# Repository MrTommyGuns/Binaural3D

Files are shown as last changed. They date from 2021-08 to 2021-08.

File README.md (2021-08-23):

# Binaural3D
TFG: "Diseño de un Micrófono Biaural para Captación de Sonido Realista"

## Resumen

Diseño e implementación de un micrófono
biaural para la captación de sonidos realistas. Consta de electrónica analógica y un diseño
tridimensional realizado mediante impresión 3D FDM.

Para el diseño 3D se partió de recursos libres de derechos para la modificación, a partir
de los cuales se llevó a cabo una total remodelación para garantizar un sistema modular
con el que realizar diferentes grabaciones dependiendo de las suposiciones requeridas. Por
consiguiente, mediante el intercambio de piezas de una misma unidad se puede variar la
ubicación de la cápsula microfónica en el oído emulado, el tamaño y forma de las orejas,
siendo estos parámetros fundamentales para generar una sensación psicoacústica correcta
para cada individuo. De este modo, se consigue un sistema muy versátil.

El circuito electrónico consiste en un preamplificador de varias etapas, donde se amplifica
la señal recogida por las cápsulas microfónicas situadas en el diseño 3D que recrea
una cabeza, simulando la captación de sonidos del oído humano. Para la implementación
de este circuito electrónico, se han llevado a cabo diferentes etapas. En primer lugar se
realizó el estudio de las cápsulas microfónicas de tipo electret, para su posterior acondicionamiento
y amplificación. Posteriormente mediante simulación se realizó un primer
circuito preamplificador simple y el primer prototipo mediante protoboard. Una vez alcanzados
unos resultados satisfactorios se inició el proceso de diseño de la PCB, incrementando
la complejidad del circuito mediante la implementación de nuevas configuraciones
de amplificación y la adhesión de un sistema de balanceo de la señal. Se realizaron una serie
de medidas eléctricas para la verificación del correcto funcionamiento y se corrigieron
los errores encontrados. Finalmente, se realizó el circuito final junto a la PCB definitiva y
se realizaron test de funcionamiento y caracterización.

CabezaFull4

PruebaSegundoPrototipo





## Vídeo

https://youtu.be/iz7Ld4p7Zro

https://youtu.be/ZWAR-ZuT80Q

## Autor

### Tomás Criado Galache

## Palabras clave

Micrófono Biaural; Preamplificador; Impresión 3D

Key words: Binaural Microphone; Preamplifier; 3D Print

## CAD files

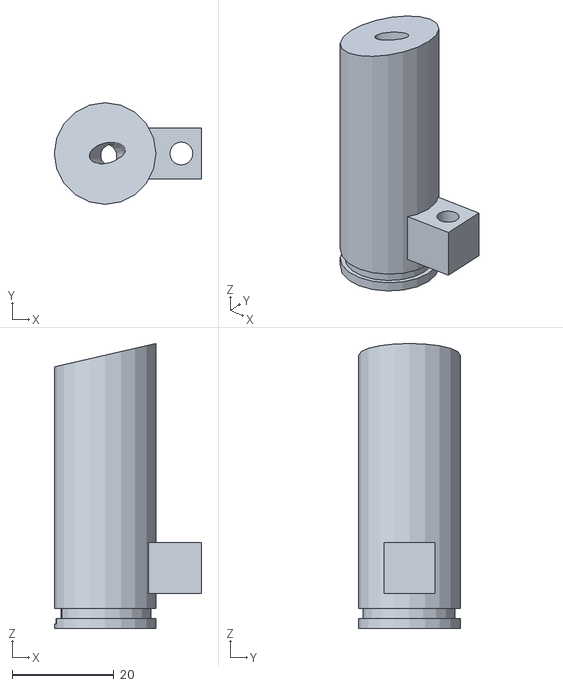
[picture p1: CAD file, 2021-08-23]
3D/Biaural_capsulemodule_R_V2.stl
29.0 x 20.0 x 56.1

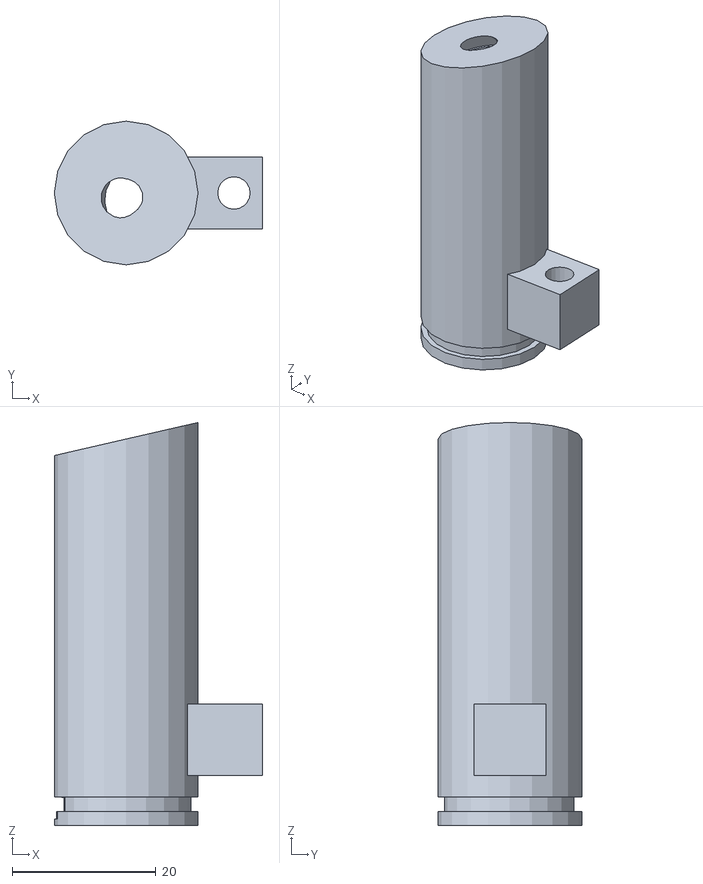
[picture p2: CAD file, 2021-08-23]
3D/Biaural_capsulemodule_R_No_Conducto.stl
29.0 x 20.0 x 56.1

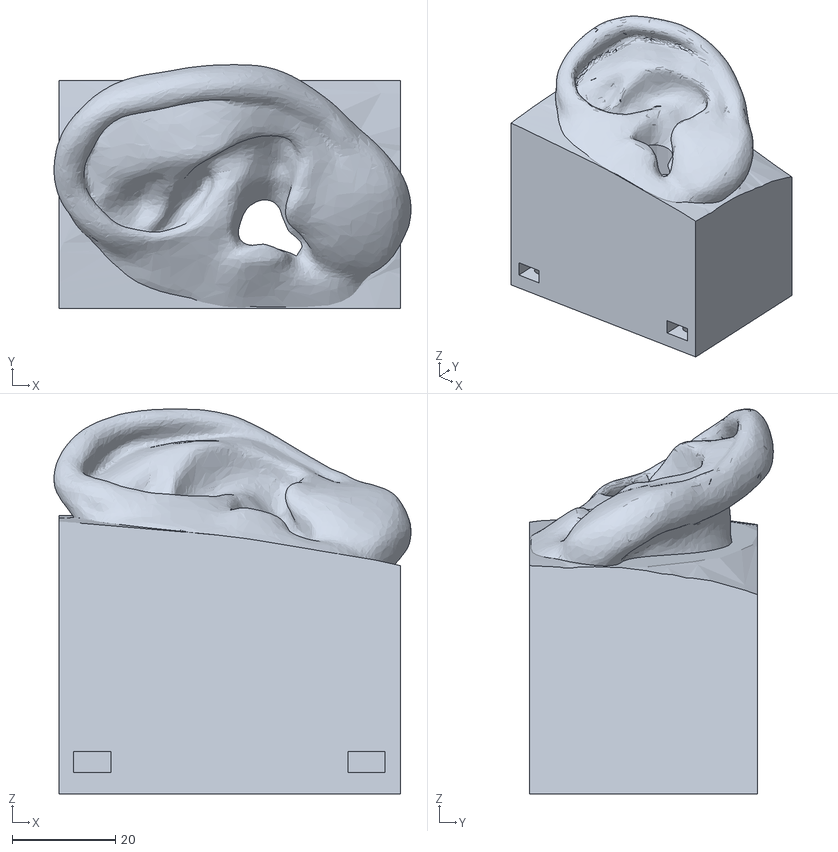
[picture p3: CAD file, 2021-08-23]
3D/Biaural_L_ear_V3.stl
69.0 x 47.1 x 74.4

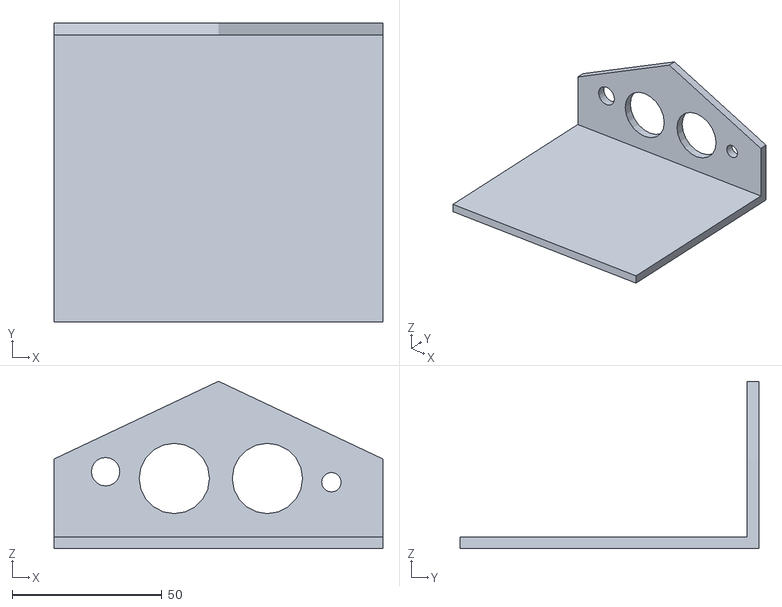
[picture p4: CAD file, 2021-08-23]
3D/Frontal Electronica.stl
110.0 x 100.0 x 56.0

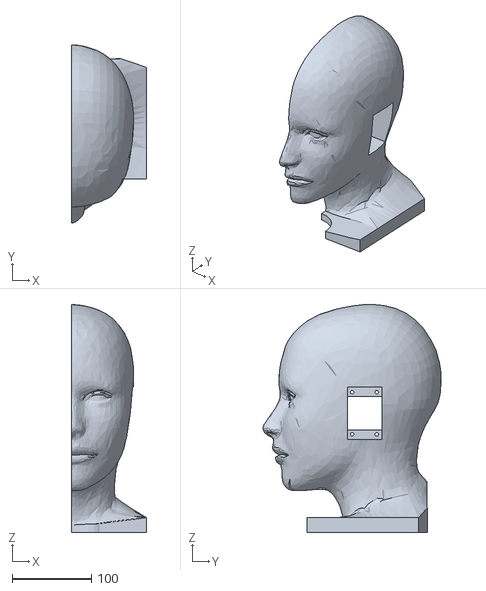
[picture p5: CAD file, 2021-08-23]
3D/Biaural_head_L_V4.stl
94.0 x 224.3 x 287.0

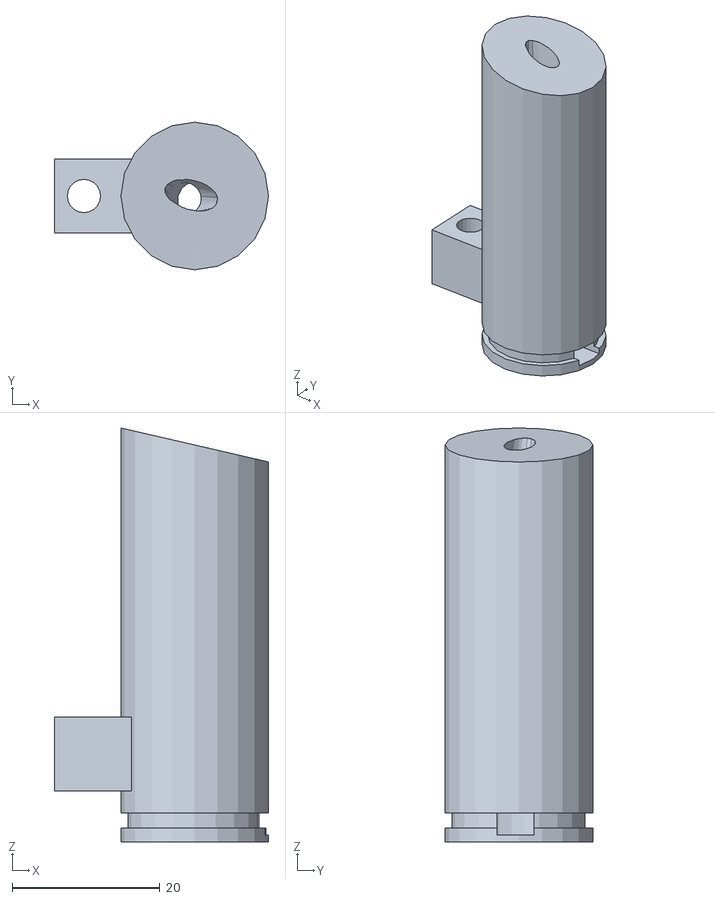
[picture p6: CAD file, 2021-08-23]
3D/Biaural_capsulemodule_L_V2.stl
29.0 x 20.0 x 56.1

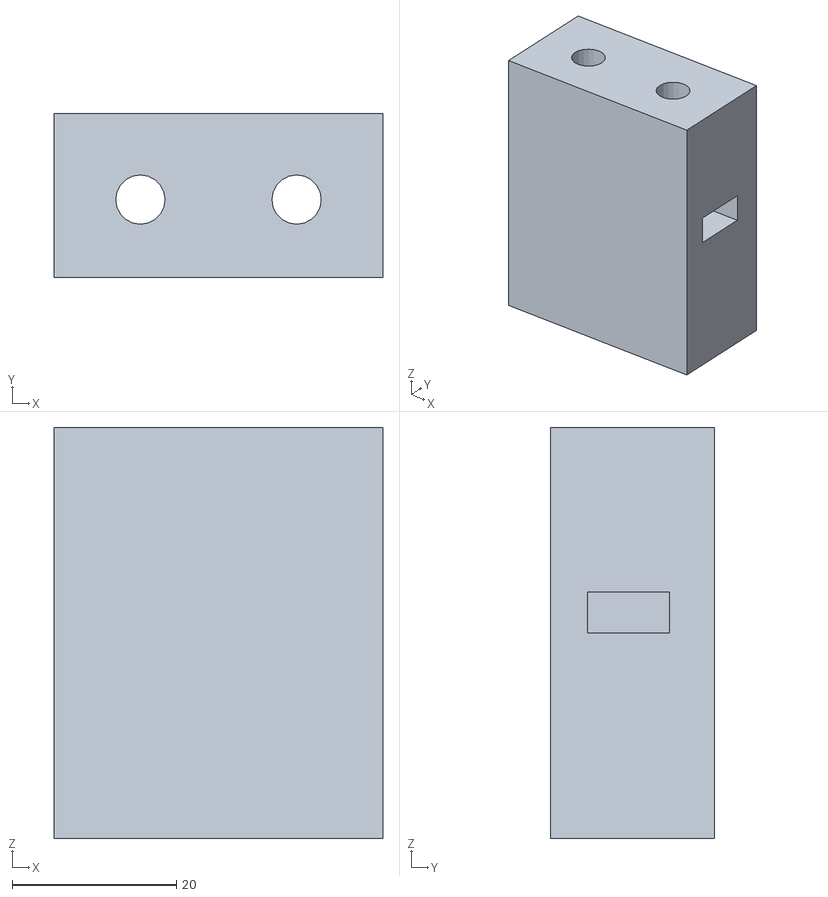
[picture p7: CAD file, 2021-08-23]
3D/Biaural_head_V4_Union.stl
40.0 x 20.0 x 50.0

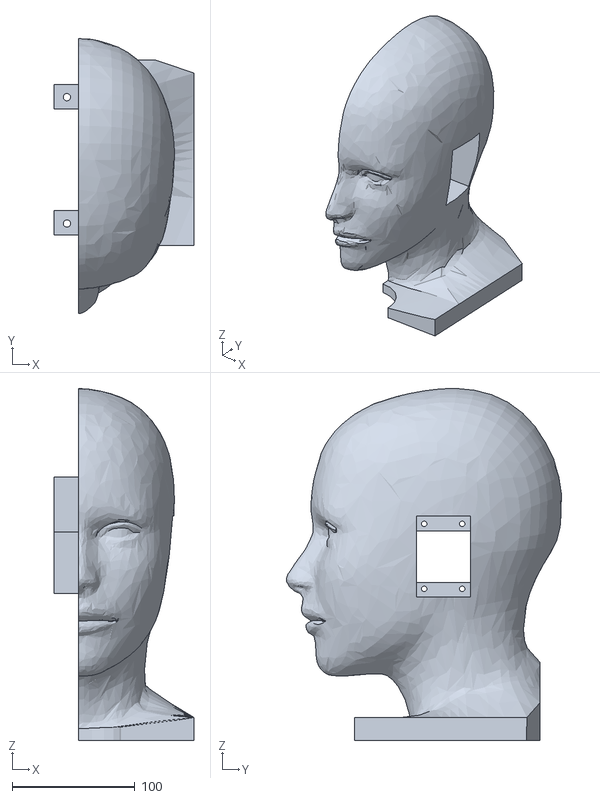
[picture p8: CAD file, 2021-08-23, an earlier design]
3D/Biaural_head_L_V3.stl
114.1 x 224.3 x 287.0

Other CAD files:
3D/Biaural_capsulemodule_L_No_Conducto.stl
3D/Biaural_head_R_V3.stl
3D/Biaural_R_ear_V3.stl

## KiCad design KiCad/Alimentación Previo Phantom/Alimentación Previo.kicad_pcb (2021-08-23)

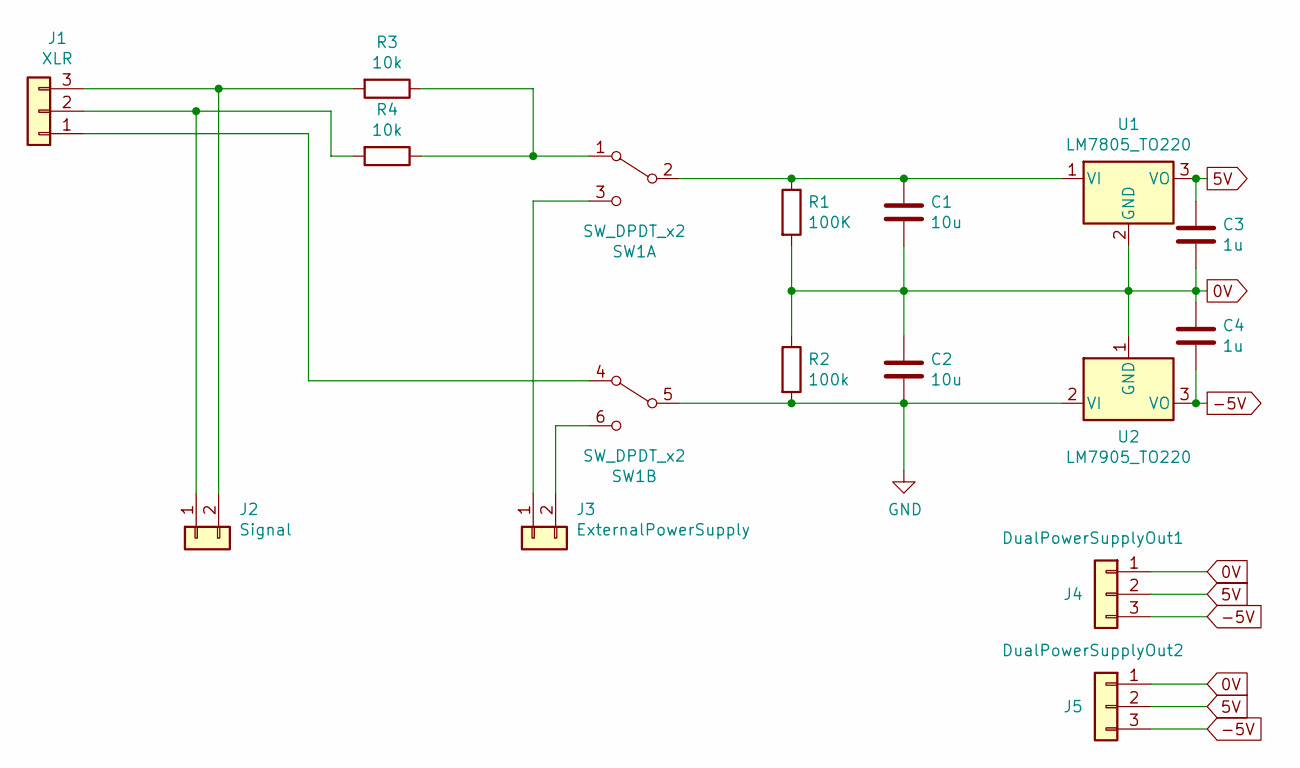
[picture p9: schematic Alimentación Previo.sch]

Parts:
C1, C2: 10u; CP_Radial_D8.0mm_P5.00mm
C3, C4: 1u; CP_Radial_D8.0mm_P5.00mm
J1: XLR; SolderWire-0.5sqmm_1x03_P4.8mm_D0.9mm_OD2.3mm
J2: Signal; SolderWire-0.5sqmm_1x02_P4.8mm_D0.9mm_OD2.3mm
J3: ExternalPowerSupply; SolderWire-0.5sqmm_1x02_P4.8mm_D0.9mm_OD2.3mm
J4: DualPowerSupplyOut1; SolderWire-0.5sqmm_1x03_P4.8mm_D0.9mm_OD2.3mm
J5: DualPowerSupplyOut2; SolderWire-0.5sqmm_1x03_P4.8mm_D0.9mm_OD2.3mm
R1: 100K; R_Axial_DIN0207_L6.3mm_D2.5mm_P10.16mm_Horizontal
R2: 100k; R_Axial_DIN0207_L6.3mm_D2.5mm_P10.16mm_Horizontal
R3, R4: 10k; R_Axial_DIN0207_L6.3mm_D2.5mm_P10.16mm_Horizontal
SW1: SW_DPDT_x2; SW_E-Switch_EG1271_DPDT
U1: LM7805_TO220; TO-220-3_Vertical
U2: LM7905_TO220; TO-220-3_Vertical

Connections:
0V: C1.2, C2.1, C3.2, C4.1, J4.1, J5.1, R1.2, R2.1, U1.2 (GND), U2.1 (GND)
5V: C3.1, J4.2, J5.2, U1.3 (VO)
-5V: C4.2, J4.3, J5.3, U2.3 (VO)
GND: C2.2, R2.2, SW1.5 (B), U2.2 (VI)
unnamed: C1.1, R1.1, SW1.2 (B), U1.1 (VI)
unnamed: J1.1, SW1.4 (A)
unnamed: J1.2, J2.1, R4.2
unnamed: J1.3, J2.2, R3.2
unnamed: J3.1, SW1.3 (C)
unnamed: J3.2, SW1.6 (C)
unnamed: R3.1, R4.1, SW1.1 (A)

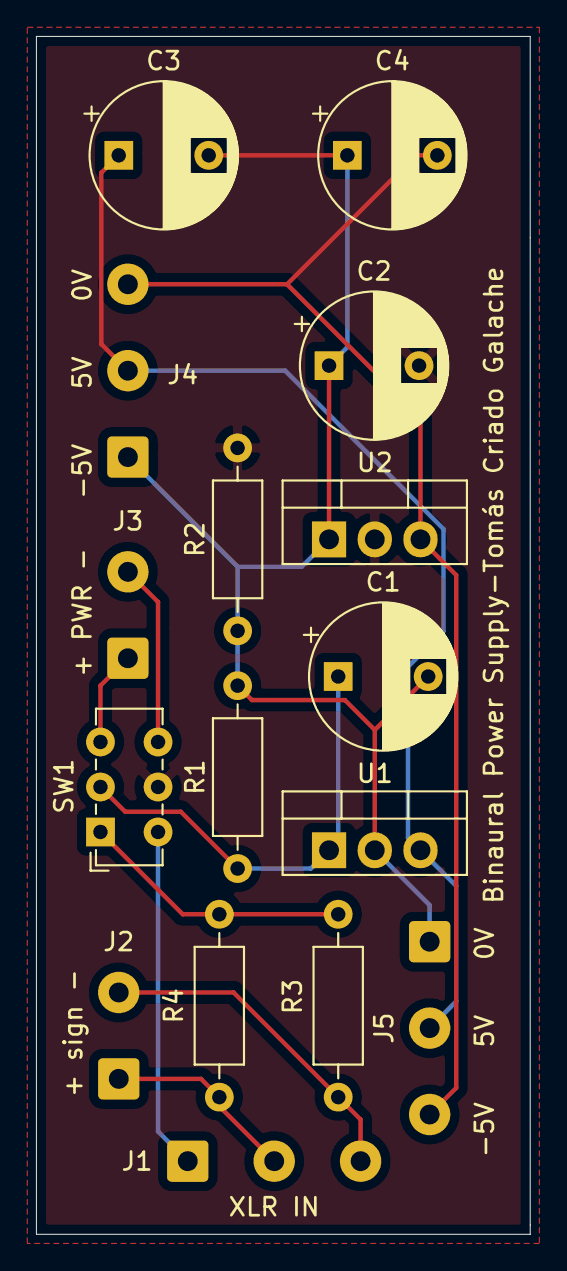
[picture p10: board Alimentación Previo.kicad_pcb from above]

Board: 2 copper layers, 27.4 x 66.5 mm, 16 parts (0 on the bottom side), 11 nets.

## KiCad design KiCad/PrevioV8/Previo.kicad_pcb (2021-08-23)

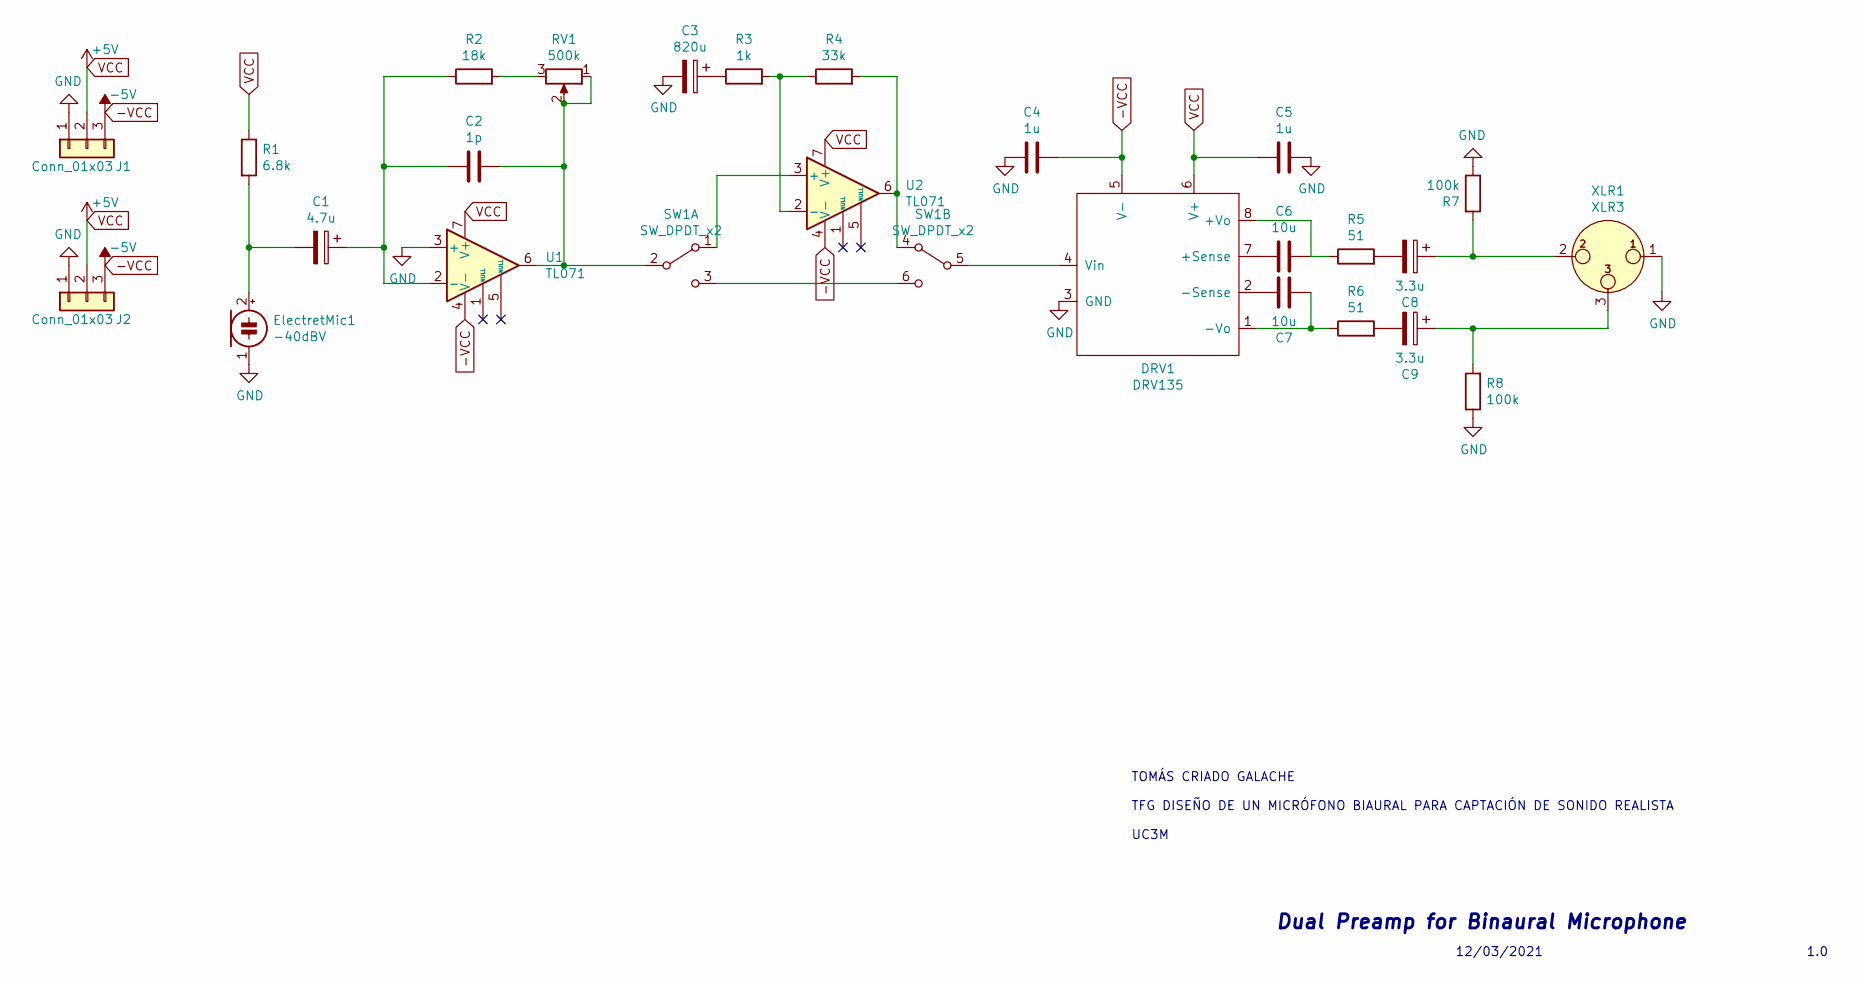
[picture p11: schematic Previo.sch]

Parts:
C1: 4.7u; CP_Radial_D8.0mm_P5.00mm
C2: 1p; C_Rect_L7.0mm_W4.5mm_P5.00mm
C3: 820u; CP_Radial_D8.0mm_P5.00mm
C4, C5: 1u; C_Rect_L7.0mm_W4.5mm_P5.00mm
C6, C7: 10u; C_Rect_L7.0mm_W4.5mm_P5.00mm
C8, C9: 3.3u; CP_Radial_D8.0mm_P5.00mm
DRV1: DRV135; DIP-8_W7.62mm_LongPads
ElectretMic1: -40dBV; PhoenixContact_MSTBVA_2,5_2-G_1x02_P5.00mm_Vertical
J1, J2: Conn_01x03; SolderWire-0.5sqmm_1x03_P4.8mm_D0.9mm_OD2.3mm
R1: 6.8k; R_Axial_DIN0207_L6.3mm_D2.5mm_P10.16mm_Horizontal
R2: 18k; R_Axial_DIN0207_L6.3mm_D2.5mm_P10.16mm_Horizontal
R3: 1k; R_Axial_DIN0207_L6.3mm_D2.5mm_P10.16mm_Horizontal
R4: 33k; R_Axial_DIN0207_L6.3mm_D2.5mm_P10.16mm_Horizontal
R5, R6: 51; R_Axial_DIN0207_L6.3mm_D2.5mm_P10.16mm_Horizontal
R7, R8: 100k; R_Axial_DIN0207_L6.3mm_D2.5mm_P10.16mm_Horizontal
RV1: 500k; SolderWire-0.5sqmm_1x03_P4.8mm_D0.9mm_OD2.3mm
SW1: SW_DPDT_x2; SolderWire-0.5sqmm_1x06_P4.8mm_D0.9mm_OD2.3mm
U1, U2: TL071; DIP-8_W7.62mm_LongPads
XLR1: XLR3; SolderWire-0.5sqmm_1x03_P4.8mm_D0.9mm_OD2.3mm

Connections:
-VCC: C4.1, DRV1.5 (V-), J1.3, J2.3, U1.4 (V-), U2.4 (V-)
GND: C3.2, C4.2, C5.1, DRV1.3 (GND), ElectretMic1.1 (-), J1.1, J2.1, R7.1, R8.1, U1.3 (+), XLR1.1
unnamed: C1.1, C2.2, R2.1, U1.2 (-)
unnamed: C1.2, ElectretMic1.2 (+), R1.2
unnamed: C2.1, RV1.1, RV1.2, SW1.2 (B), U1.6
unnamed: C3.1, R3.1
unnamed: C6.1, DRV1.8 (+Vo), R5.1
unnamed: C6.2, DRV1.7 (+Sense)
unnamed: C7.1, DRV1.2 (-Sense)
unnamed: C7.2, DRV1.1 (-Vo), R6.1
unnamed: C8.1, R7.2, XLR1.2
unnamed: C8.2, R5.2
unnamed: C9.1, R8.2, XLR1.3
unnamed: C9.2, R6.2
unnamed: DRV1.4 (Vin), SW1.5 (B)
unnamed: R2.2, RV1.3
unnamed: R3.2, R4.1, U2.2 (-)
unnamed: R4.2, SW1.4 (A), U2.6
unnamed: SW1.1 (A), U2.3 (+)
unnamed: SW1.3 (C), SW1.6 (C)
VCC: C5.2, DRV1.6 (V+), J1.2, J2.2, R1.1, U1.7 (V+), U2.7 (V+)

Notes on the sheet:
12/03/2021
1.0
Dual Preamp for Binaural Microphone
TOMÁS CRIADO GALACHE TFG DISEÑO DE UN MICRÓFONO BIAURAL PARA CAPTACIÓN DE SONIDO REALISTA UC3M

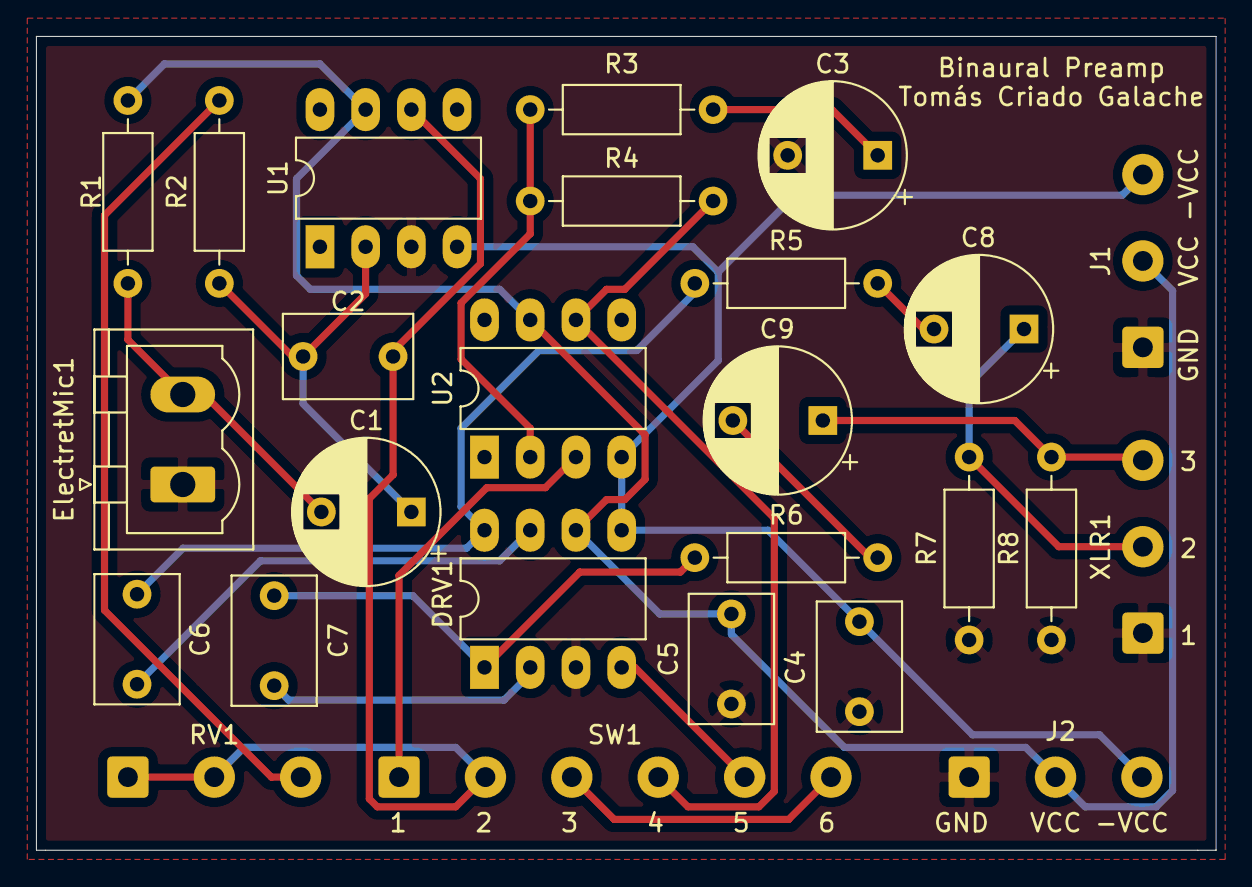
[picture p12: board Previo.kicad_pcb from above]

Board: 2 copper layers, 65.5 x 45.2 mm, 26 parts (0 on the bottom side), 21 nets.

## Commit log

2021-08-23 Archivos KiCad
    [Alimentación Previo.kicad_pcb, Alimentación Previo.sch, Previo.kicad_pcb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]
2021-08-23 Diseños 3D
    [Biaural_L_ear_V3.stl, Biaural_R_ear_V3.stl, Biaural_capsulemodule_L_No_Conducto.stl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]
